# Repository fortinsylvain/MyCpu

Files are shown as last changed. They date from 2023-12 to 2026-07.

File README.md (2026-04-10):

# Homebrew CPU Project

I built this CPU at home using 74LS logic ICs, EEPROMs, RAMs and GALs, driven by curiosity and a desire to understand processor design at a fundamental level.

---

## 🔧 Project Overview
My goal was to create a **fully functional CPU** using a **1-bit ALU**. While this results in relatively slow execution speeds, it allows me to explore the control and datapath mechanisms in detail.

- All **microcode** for the CPU is stored in **two binary files** programmed into 2864 EEPROM chips.
- A custom **microassembler** generates these micro-instructions.

---

## 🧠 Custom CPU PCB Update

After validating the core architecture on a wire-wrap prototype, the custom PCB version of the CPU is now complete. The boards were professionally fabricated by PCBWay, thanks to a generous sponsorship offered by Liam from their marketing team, who discovered the project on GitHub. This support helped transition the design from a hand-built prototype to a professionally produced PCB.

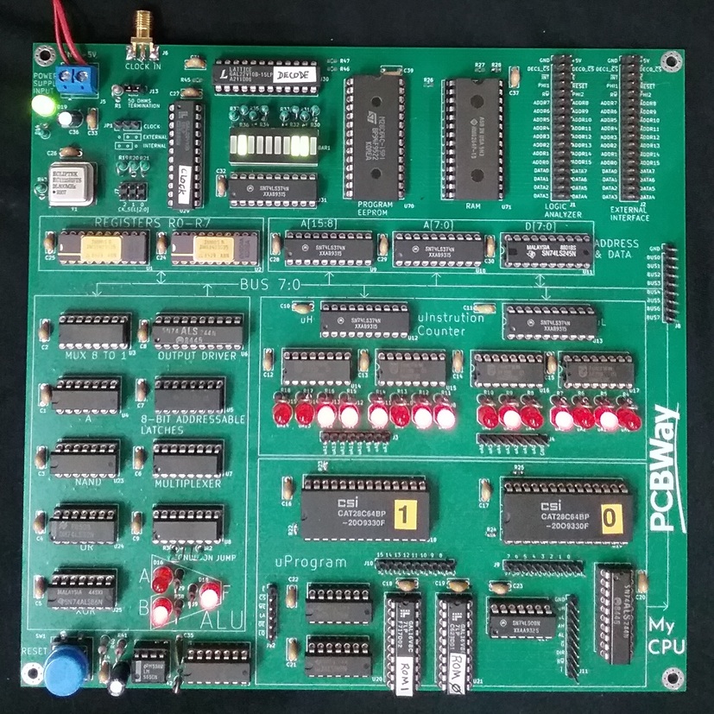
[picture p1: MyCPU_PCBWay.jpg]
KiCad PCB Design


## 🛠️ PCBWay Manufacturing Review

I’m happy to share my experience working with PCBWay for manufacturing the custom PCB version of my CPU project. Here's a quick summary of how it went:

First, I transferred the handwritten schematic into KiCad, then completed the routing for each required part. I was able to find all the necessary components on AliExpress. After carefully checking my Gerber files, it was time to send the design to the factory.

🔁 I was genuinely impressed by PCBWay’s one-click KiCad integration — all design files were submitted automatically to the PCBWay factory with a single click. No file packaging, no ZIP uploads — just click and go! The ordering process was fast and seamless.

🌐 The web interface was intuitive and transparent, allowing me to track each step of the production process in real time.

📦 The PCBs arrived astonishingly quickly, properly boxed and well-protected with excellent packaging. Although I ordered 5 boards, PCBWay generously included 6 — a thoughtful bonus!

The soldering process went smoothly. I used footprints optimized for hand soldering, with larger pads to make it easier to work with. Only a couple of 0603 surface-mount resistors are present on the board.

🔌 First power-on: the board worked on the first try!
I reused the same microcode and program EEPROM, along with the GAL, that were previously tested on the wire-wrap prototype — total success.

Since the new board has a solid ground plane, I expect it will run faster than the prototype, with improved signal integrity. I plan to validate this with an oscilloscope soon — stay tuned for updates!

🌍 There’s a strong online community around PCBWay, full of shared open-source hardware projects — very inspiring!

## 🧠 Board design files
[Download Schematic PDF](Kicad/MyCPU_Schematic.pdf)

## 🧵 Wire-Wrap Prototype

Before moving to a PCB, I built a **wire-wrap prototype** to test the design on real hardware. This stage was essential for debugging the microcode, verifying timing, and refining the instruction set.

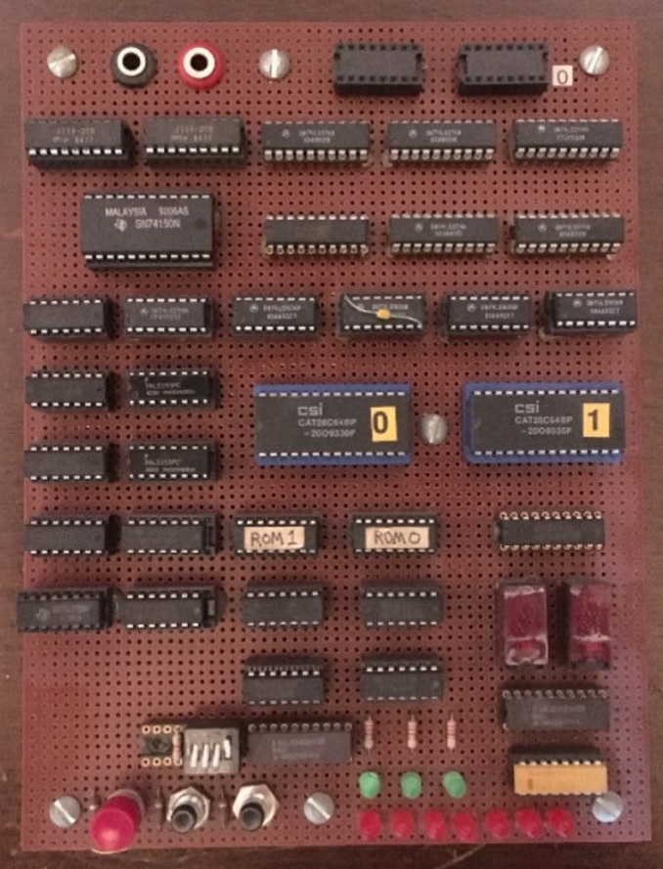
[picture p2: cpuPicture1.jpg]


Here’s a picture of the back — a lot of patience was required!
Amazingly, it's still holding together and executing code after 30 years.

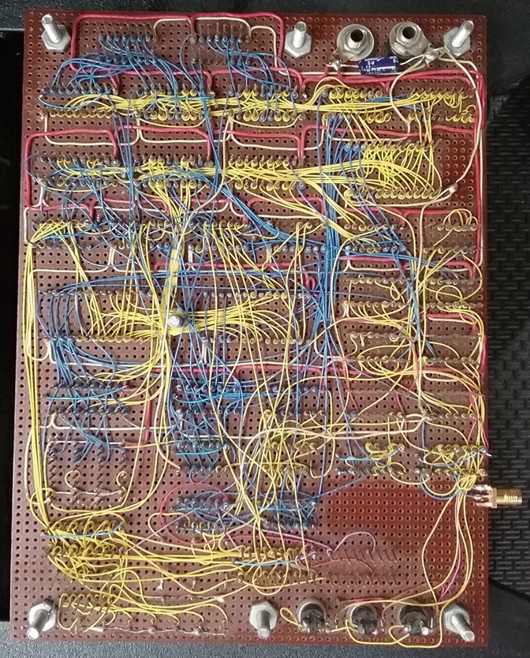
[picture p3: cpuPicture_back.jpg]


Wire-wrapping made it easier to make changes during development while still providing a reliable and compact way to interconnect components.

---

## Microcode and Assembler

💾 [Download Microcode Source](uCodeAssembler/urom.lst)  
💾 [Download Microcode Assembler](uCodeAssembler/UctMicroAssembler/Program.cs)  
💾 [Download Opcode Assembler](opCodeAssembler/Program.cs)  
💾 [Download Diagnostic Program](opCodeAssembler/examples/diag.asm)  

---
## GAL source files
In the PCB version of MyCPU i make use of programmable logic devices (GALs) for clock phase generation, address decoding, and microcode ROM decoding tables.
The source files were compiled using WinCupl, and the chips were programmed using a TL866II Plus programmer.

💾 [Download GAL22V10 Clock](GAL/Clock/CLOCK.PLD)
💾 [Download GAL22V10 Decoder](GAL/Decoder/DECODER.PLD)
💾 [Download GAL16V8 ROM0](GAL/Rom0/ROM0.PLD)
💾 [Download GAL16V8 ROM1](GAL/Rom1/ROM1.PLD)

## 🧠 Register Implementation on RAM

The design uses address-mapped RAM to support the CPU’s operation. This approach saves chip count, though at the cost of execution speed.

The following registers are implemented in RAM:
- Instruction Pointer
- Register A
- Carry Flag
- Equal Flag
- Index Register
- Stack Pointer
- The Stack

Here is the memory address map:

0000H - 17FFH Total RAM space
-----------------------------
* 0000H - 17FFH Total RAM space
* 0000H - 00FFH Stack
* 0100H - 17EF  Free for application
* 1FF0H SP      Stack Pointer 8 bit
* 1FF1H JSH     Temporary storage for JSR MSB address
* 1FF2H JSL          "       "     "   "  LSB    "
* 1FF3H XH      Index Register MSB
* 1FF4H XL      Index Register LSB
* 1FFAH E       bit<0> Equal Status bit
* 1FFBH C       bit<0> Carry Status bit
* 1FFCH A       Register
* 1FFEH IPH	    Instruction Pointer MSB
* 1FFFH IPL     Instruction Pointer MSB
* C000H         LED port
* E000H - F000H EEPROM for application program

---

## System Overview

### Top-Level Architecture Diagram  
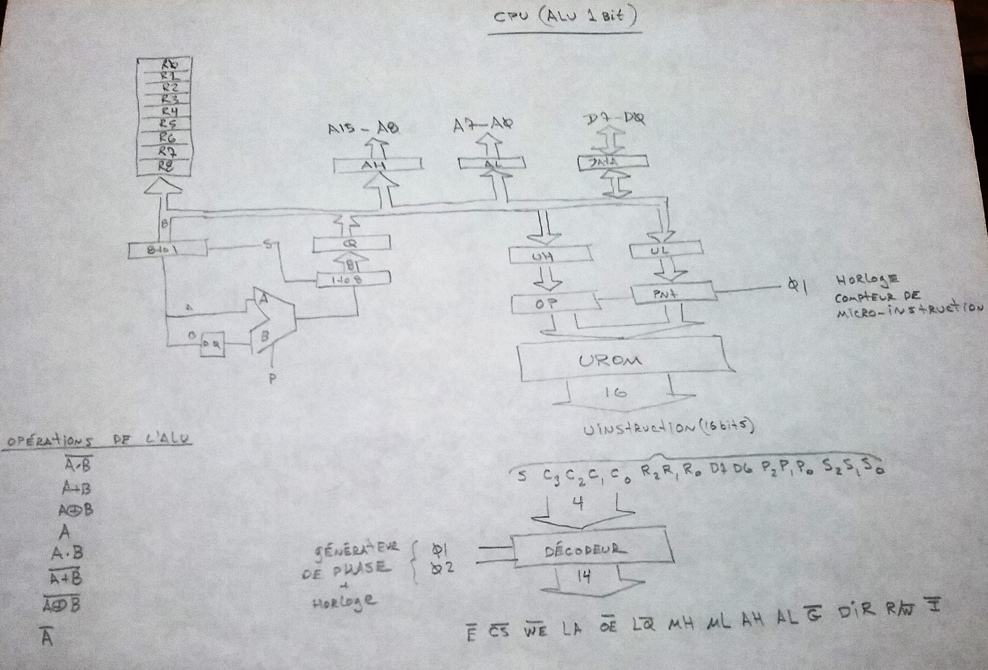
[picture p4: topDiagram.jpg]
Top-Level Diagram


### Hand-Written CPU Schematic  
When I started this project back in 1995, I didn’t have access to schematic capture software or a decent computer that could run it. I only had an IBM Personal Computer XT, so I used pen and paper to sketch how the electronic components were connected.

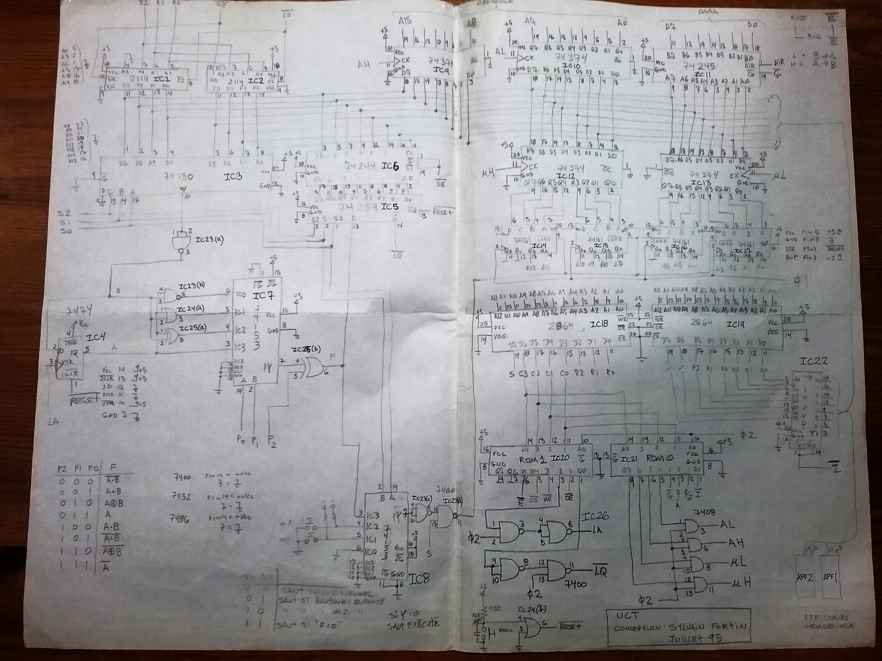
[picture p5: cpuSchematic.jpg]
CPU Schematic


### CPU Board Layout View  
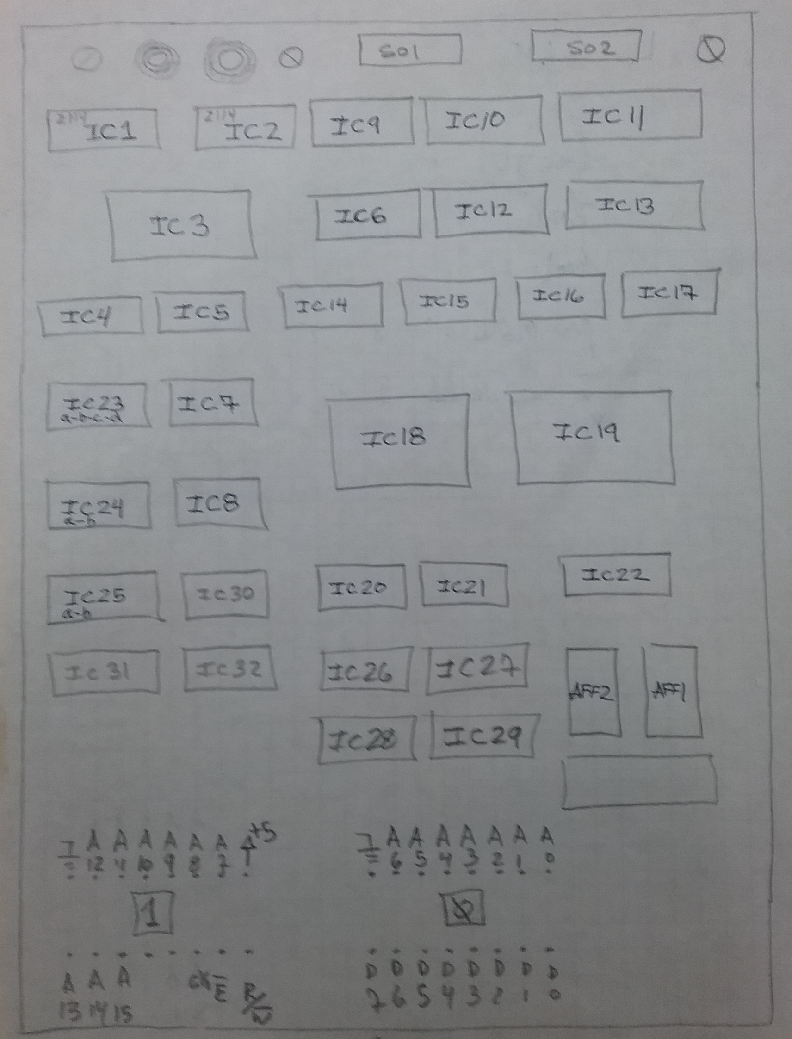
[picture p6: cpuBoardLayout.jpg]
CPU Board Layout


---

## Microcode and Control ROMs

The microcode is stored in two 2864 EEPROM ICs.
Originally, a BASIC program was used to translate a text file of micro-instructions into a .hex file.
A homemade EEPROM programmer was built to write these files via the parallel port of an IBM PC XT.

Today, a modern C# program performs the same translation into .hex format for programming.

The ROM decoding table encodes how data moves between components. This reduces the number of control bits required by expanding microcode control using external PROMs.

- ROM chips: **IC20** and **IC21** (74S188, 256×1 Open Collector PROMs)
- These are *one-time programmable* PROMs.
- Several chips were sacrificed before the correct decoding table was finalized.

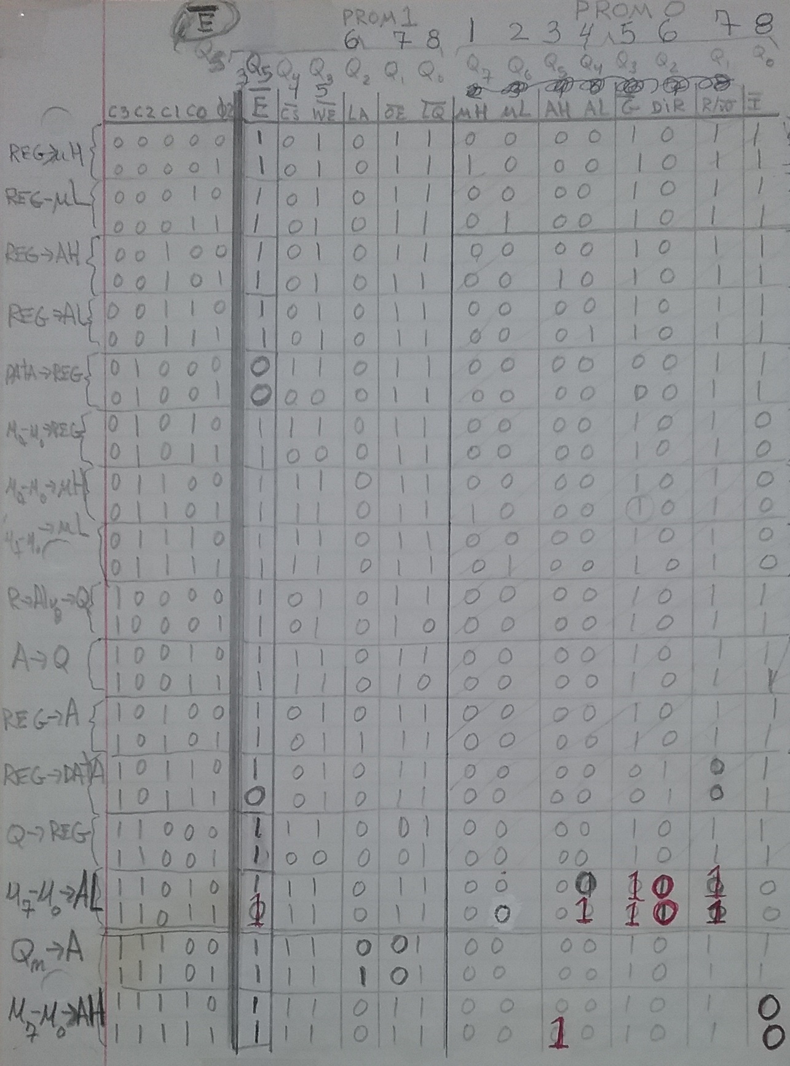
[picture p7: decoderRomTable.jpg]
Decoder ROM Table


In the PCB version of the board, two GAL16V8 replaces the PROMs to implement the decoding table, offering greater flexibility and eliminating the need for one-time programmable chips.

---

## I/O Board Schematic
Wire wrap proto required a second board to include the following:
- RAM
- EEPROM (for application program)
- LEDs for visual feedback

The PCB version includes all of these components on a single board.

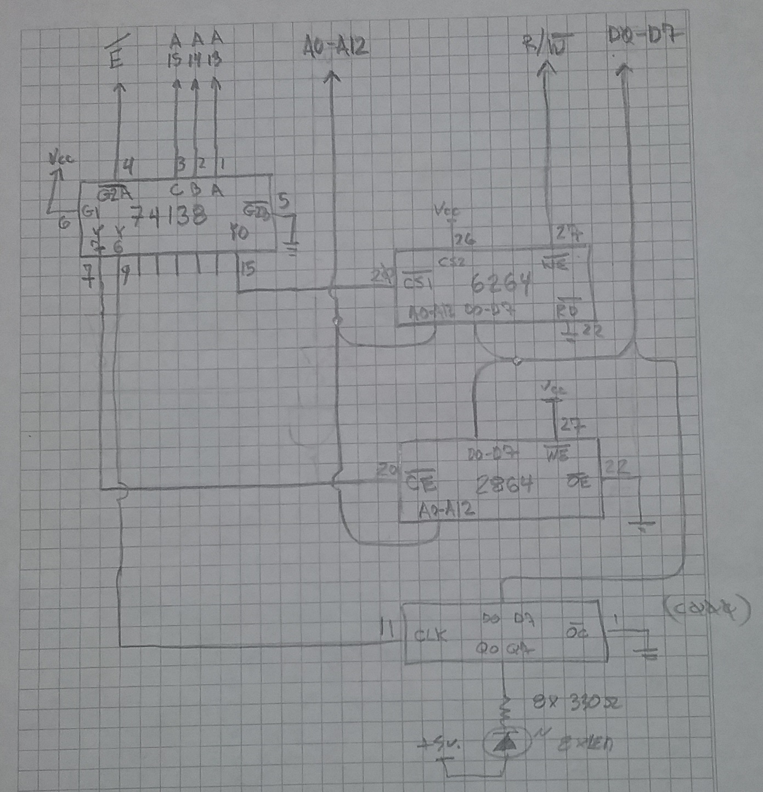
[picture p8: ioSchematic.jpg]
I/O Schematic


---

## Debugging Setup

Initially, I was single-stepping using push switches, LEDs, and a pair of classic TIL311 hex displays to monitor the 8-bit data bus on the wire-wrap prototype, but it quickly stopped being fun. When bugs like stack corruption became too tricky to debug, I decided to get an Agilent 1670G Logic Analyzer. I found one on eBay for 510 CAD, which seemed like a reasonable price—I never thought I’d own one! It’s the color LCD version, so now I get to see the word in color.

With the analyzer, I can trigger on specific conditions and even do some reverse assembly of the microcode using basic symbolic decoding. It allow recording of detailed intructions traces. Quite cool!

### Final Wire-Wrap Assembly with Logic Analyzer  
Here the Logic analyzer connected to **MyCpu** for a debug session.
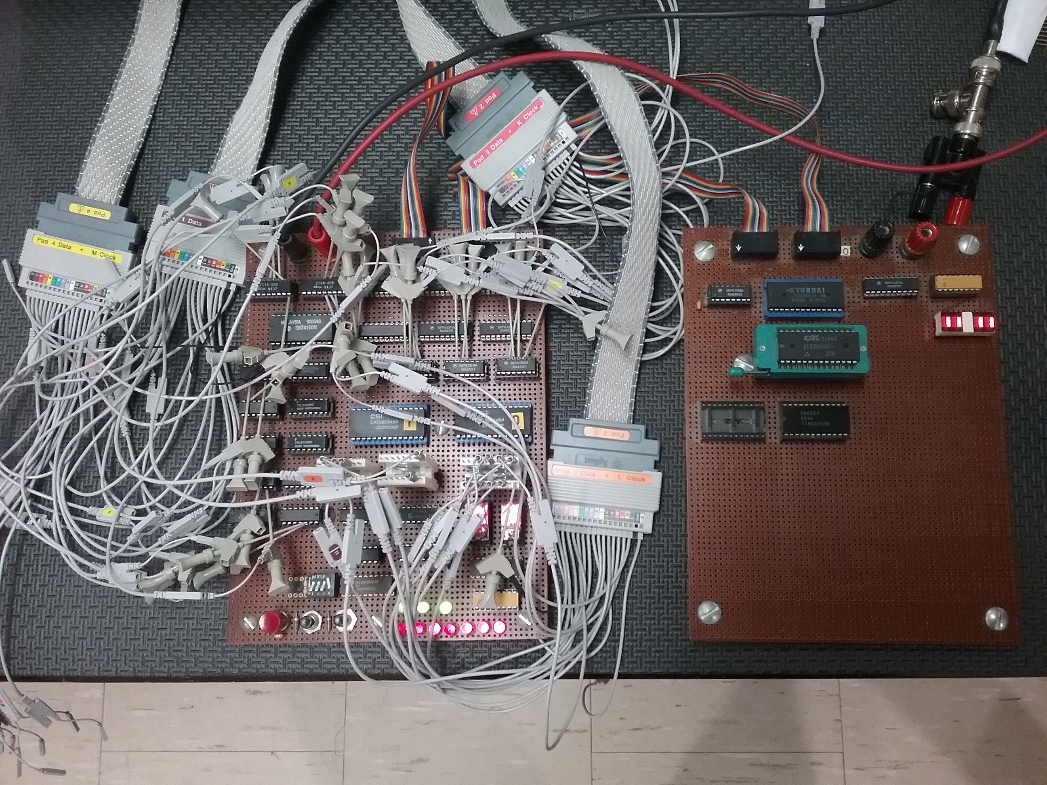
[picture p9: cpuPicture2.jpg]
Wire-Wrap and Logic Analyzer


### Microcode View on Logic Analyzer  
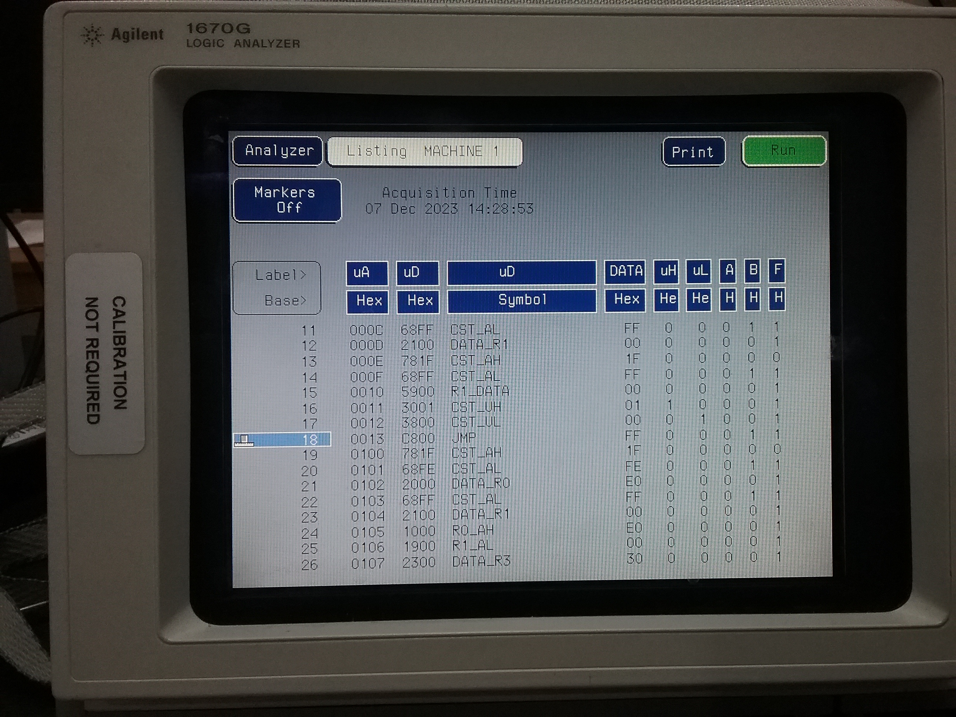
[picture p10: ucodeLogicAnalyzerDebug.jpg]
Microcode Disassembly


---

# MyCPU Instruction Set

This document describes the instruction set of the **MyCPU homebrew processor**.

---

# 📘 Overview

- 8-bit accumulator architecture (A, X registers)
- 16-bit addressing support
- Flags: E (equal/zero), C (carry)
- Stack support (SP-based)

---

# 📑 Instruction Set

---

## Data Movement

| Mnemonic | OpCode | Bytes | Mode | Flags | Description |
|---|---|---|---|---|---|
| LDA #0x** | 0x30 | 1 | Hex | - | Load immediate into A |
| LDA 0x**** | 0x2A | 2 | Hex | - | Load A from memory (absolute) |
| LDA @ | 0x2A | 2 | Symbol | - | Load A from memory (symbolic) |
| LDA (X) | 0x0A | 0 | Hex | - | Load A from memory indexed by X |
| STA 0x**** | 0x31 | 2 | Hex | - | Store A into memory (absolute) |
| STA @ | 0x31 | 2 | Symbol | - | Store A into memory (symbolic) |
| LDX 0x**** | 0x34 | 2 | Hex | - | Load X from memory |
| LDX @ | 0x34 | 2 | Symbol | - | Load X from symbolic address |
| STX 0x**** | 0x16 | 2 | Hex | - | Store X into memory |
| STX @ | 0x16 | 2 | Symbol | - | Store X into memory |

---

## Arithmetic / Logic

| Mnemonic | OpCode | Bytes | Mode | Flags | Description |
|---|---|---|---|---|---|
| ADDA #0x** | 0x2F | 1 | Hex | C | Add immediate to A |
| ADDA 0x**** | 0x29 | 2 | Hex | C | Add memory to A |
| ADDA @ | 0x29 | 2 | Symbol | C | Add memory to A (symbolic) |
| ADCA #0x** | 0x2E | 1 | Hex | C | Add immediate + carry |
| ADCA 0x**** | 0x28 | 2 | Hex | C | Add memory + carry |
| ANDA #0x** | 0x33 | 1 | Hex | - | Logical AND with A |
| ORA #0x** | 0x17 | 1 | Hex | - | Logical OR with A |
| XORA #0x** | 0x18 | 1 | Hex | - | Logical XOR with A |
| NOTA | 0x19 | 0 | Hex | - | Bitwise NOT A |
| INCA | 0x03 | 0 | Hex | E | Increment A |
| DECA | 0x20 | 0 | Hex | E | Decrement A |
| CMPA #0x** | 0x2D | 1 | Hex | E,C | Compare A with immediate |

---

## Control Flow

| Mnemonic | OpCode | Bytes | Mode | Flags | Description |
|---|---|---|---|---|---|
| JMP 0x**** | 0x32 | 2 | Hex | - | Unconditional jump |
| JMP @ | 0x32 | 2 | Symbol | - | Unconditional jump (symbolic) |
| JEQ 0x**** | 0x2C | 2 | Hex | - | Jump if equal |
| JEQ @ | 0x2C | 2 | Symbol | - | Jump if equal (symbolic) |
| JNE 0x**** | 0x2B | 2 | Hex | - | Jump if not equal |
| JNE @ | 0x2B | 2 | Symbol | - | Jump if not equal |
| JRA 0x** | 0x0C | 1 | Hex | - | Relative jump |
| JRA @ | 0x0C | 1 | Relative | - | Relative jump (symbol) |
| JRNC @ | 0x0F | 1 | Relative | - | Jump if no carry |
| JRUGE @ | 0x23 | 1 | Relative | - | Jump if unsigned ≥ |

---

## Stack & Subroutines

| Mnemonic | OpCode | Bytes | Mode | Flags | Description |
|---|---|---|---|---|---|
| JSR 0x**** | 0x06 | 2 | Hex | - | Jump to subroutine |
| JSR @ | 0x06 | 2 | Symbol | - | Jump to subroutine |
| RTS | 0x07 | 0 | Hex | - | Return from subroutine |
| PSHA | 0x24 | 0 | Hex | - | Push A to stack |
| POPA | 0x25 | 0 | Hex | - | Pop stack into A |

---

## Shift / Bit Operations

| Mnemonic | OpCode | Bytes | Mode | Flags | Description |
|---|---|---|---|---|---|
| SLLA | 0x0E | 0 | Hex | C | Shift left logical |
| SRLA | 0x0D | 0 | Hex | C | Shift right logical |
| RRCA | 0x10 | 0 | Hex | C | Rotate right through carry |
| RRC @ | 0x14 | 2 | Symbol | C | Rotate memory right |
| SRL @ | 0x15 | 2 | Symbol | C | Shift memory right |

---

## System / Misc

| Mnemonic | OpCode | Bytes | Mode | Flags | Description |
|---|---|---|---|---|---|
| NOP | 0x09 | 0 | Hex | - | No operation |
| STOP | 0x08 | 0 | Hex | - | Halt execution |
| SCF | 0x12 | 0 | Hex | C | Set carry flag |
| RCF | 0x11 | 0 | Hex | C | Reset carry flag |
| CLRA | 0x26 | 0 | Hex | E | Clear A |
| CLRX | 0x1E | 0 | Hex | E | Clear X |

---

## Memory / Data

| Mnemonic | OpCode | Bytes | Mode | Flags | Description |
|---|---|---|---|---|---|
| DB 0x** | 0x00 | 0 | Hex | - | Define byte |
| .ASCII "@" | 0x00 | 0 | Ascii | - | Store ASCII string |
| EQU 0x**** | 0x00 | 0 | Hex | - | Define constant |

---

# 🧠 Notes

- `E` = equality / zero flag
- `C` = carry flag
- `@` = symbolic addressing
- `0x****` = 16-bit address
- `#0x**` = immediate value

---

# 🚀 Generated by MyCPU Assembler

---

## Inspiration and Community

I began documenting this project after discovering **other wonderful homebrew machines** featured on:

👉 [Homebuilt CPUs WebRing](https://www.homebrewcpuring.org)

### Join the Ring!

Interested in joining the Homebuilt CPUs WebRing?

- Contact **Warren** (email address is obfuscated—replace `[at]` with `@`)
- Mention your page URL and request to join
- Add the WebRing code fragment to your site

📌 **Note:** The ring is for *actual home-built CPUs*. Emulations of commercial parts are OK.  
However, projects must be *partially or fully built*—**paper designs don’t qualify**.  
Technologies used can include **relays**, **TTL**, **CMOS**, **FPGAs**, etc.

## License
This project is licensed under the MIT License – see the [LICENSE](license.txt) file for details.

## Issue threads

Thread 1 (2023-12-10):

Rename source file to .asm

fortinsylvain, 2023-12-10:
Rename source file extension to .asm to avoid confusion and help github to associate it to assembly language.

fortinsylvain, 2023-12-14:
Code was changed.

Closed 2023-12-14.

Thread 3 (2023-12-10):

Add stack related instructions

fortinsylvain, 2023-12-10:
Current microcode version does not support operation on stack. Add micro instruction to do push, pop and jump to subroutine.

fortinsylvain, 2023-12-31:
jsr and rts was fixed in the microcode

Closed 2023-12-31.

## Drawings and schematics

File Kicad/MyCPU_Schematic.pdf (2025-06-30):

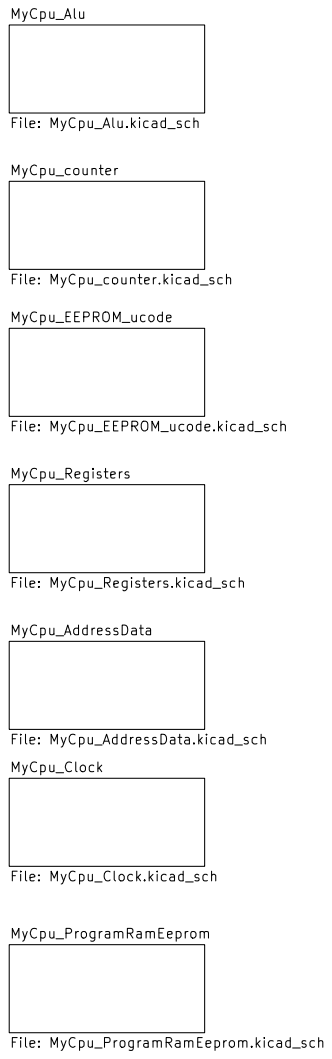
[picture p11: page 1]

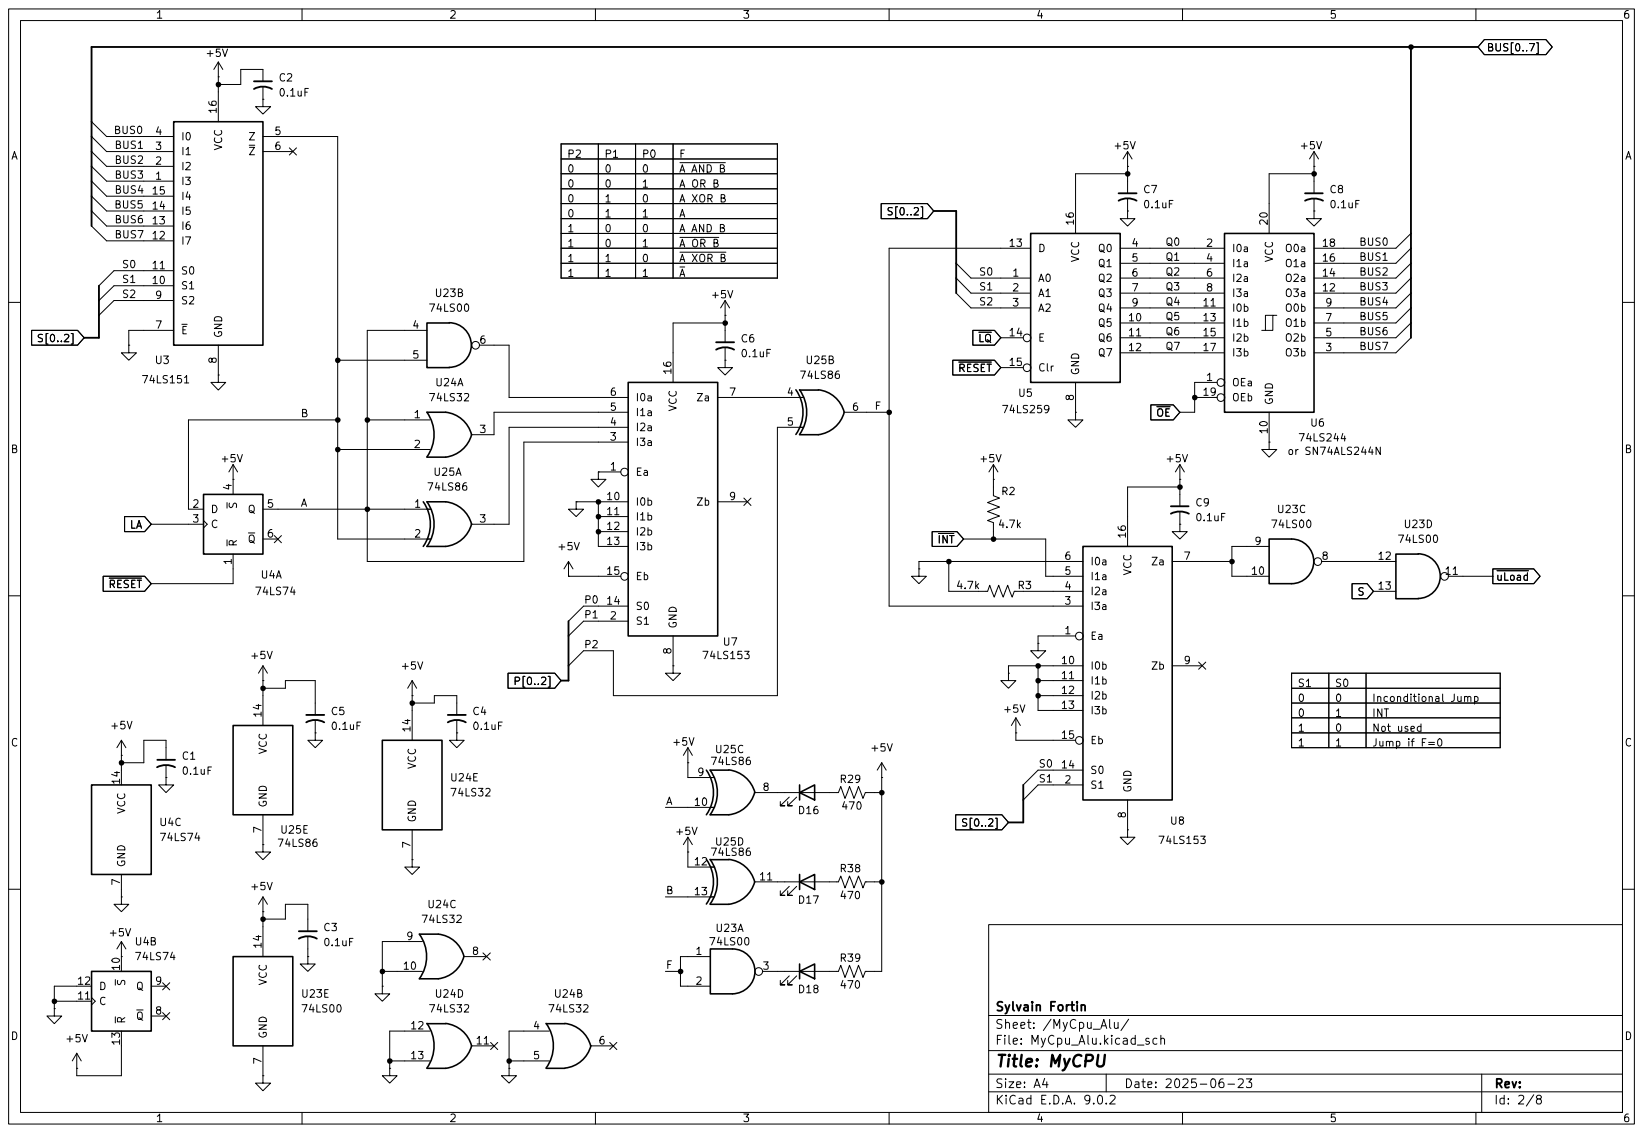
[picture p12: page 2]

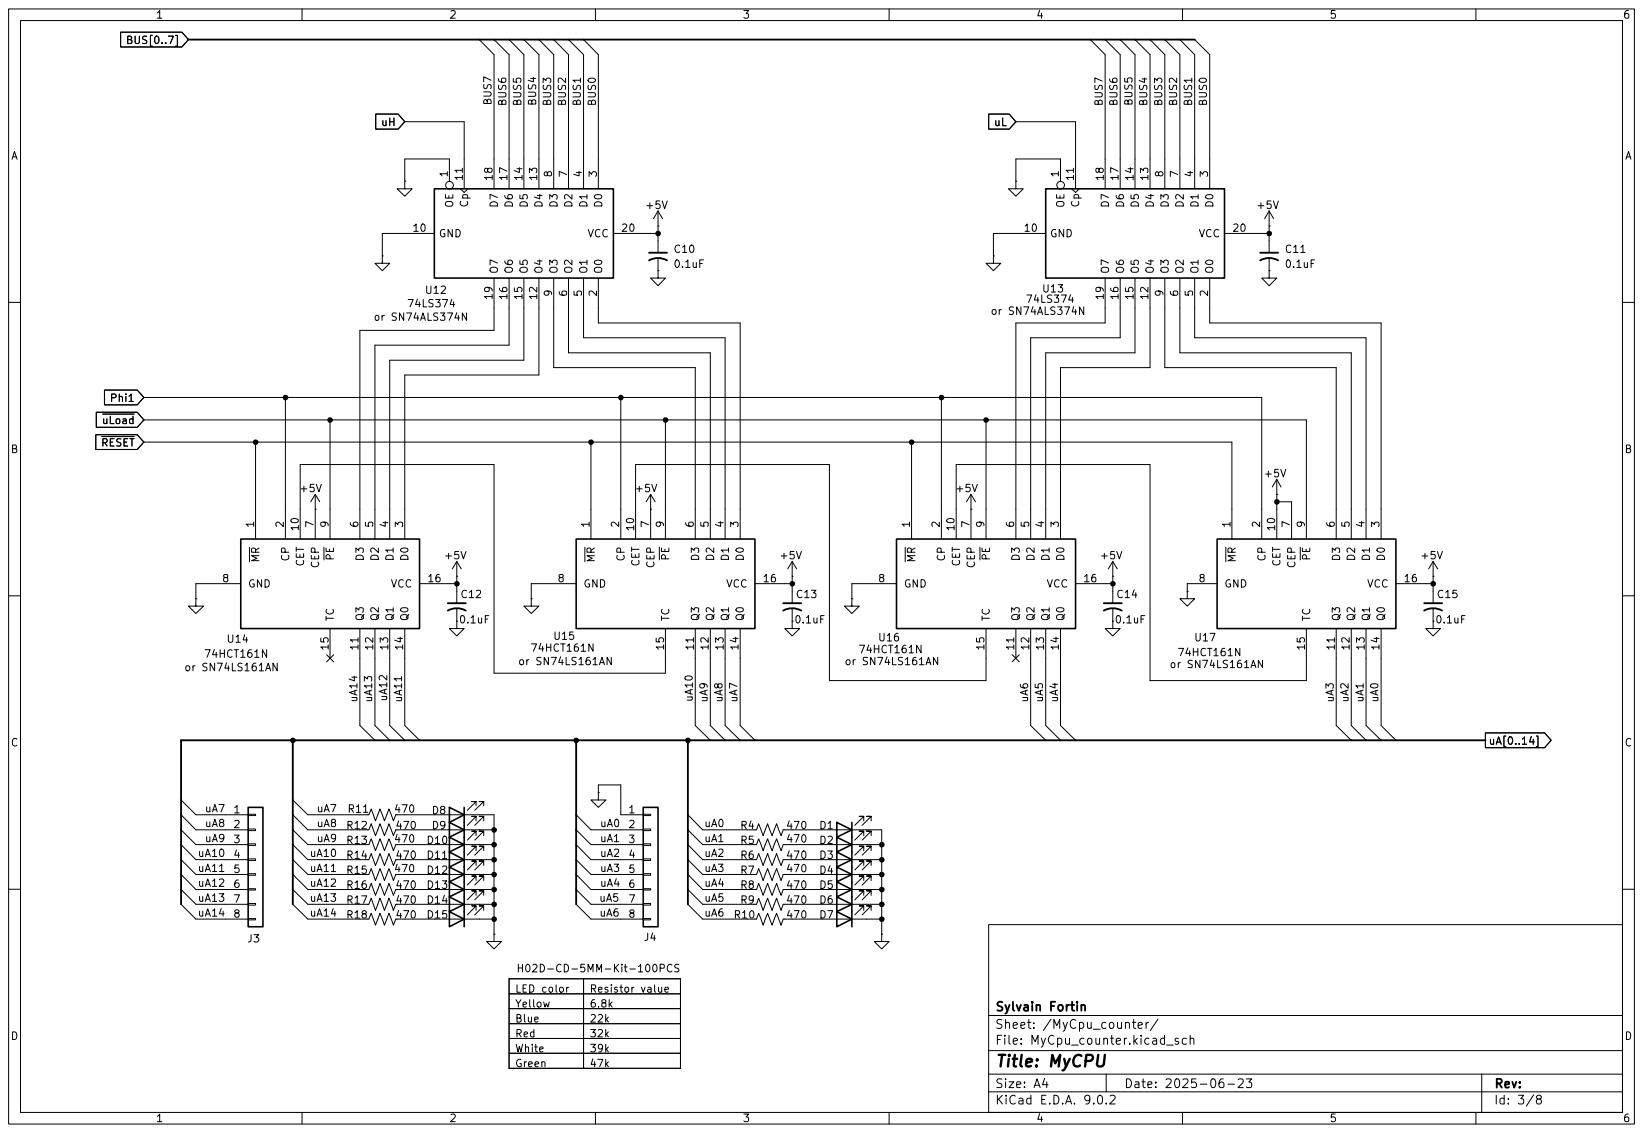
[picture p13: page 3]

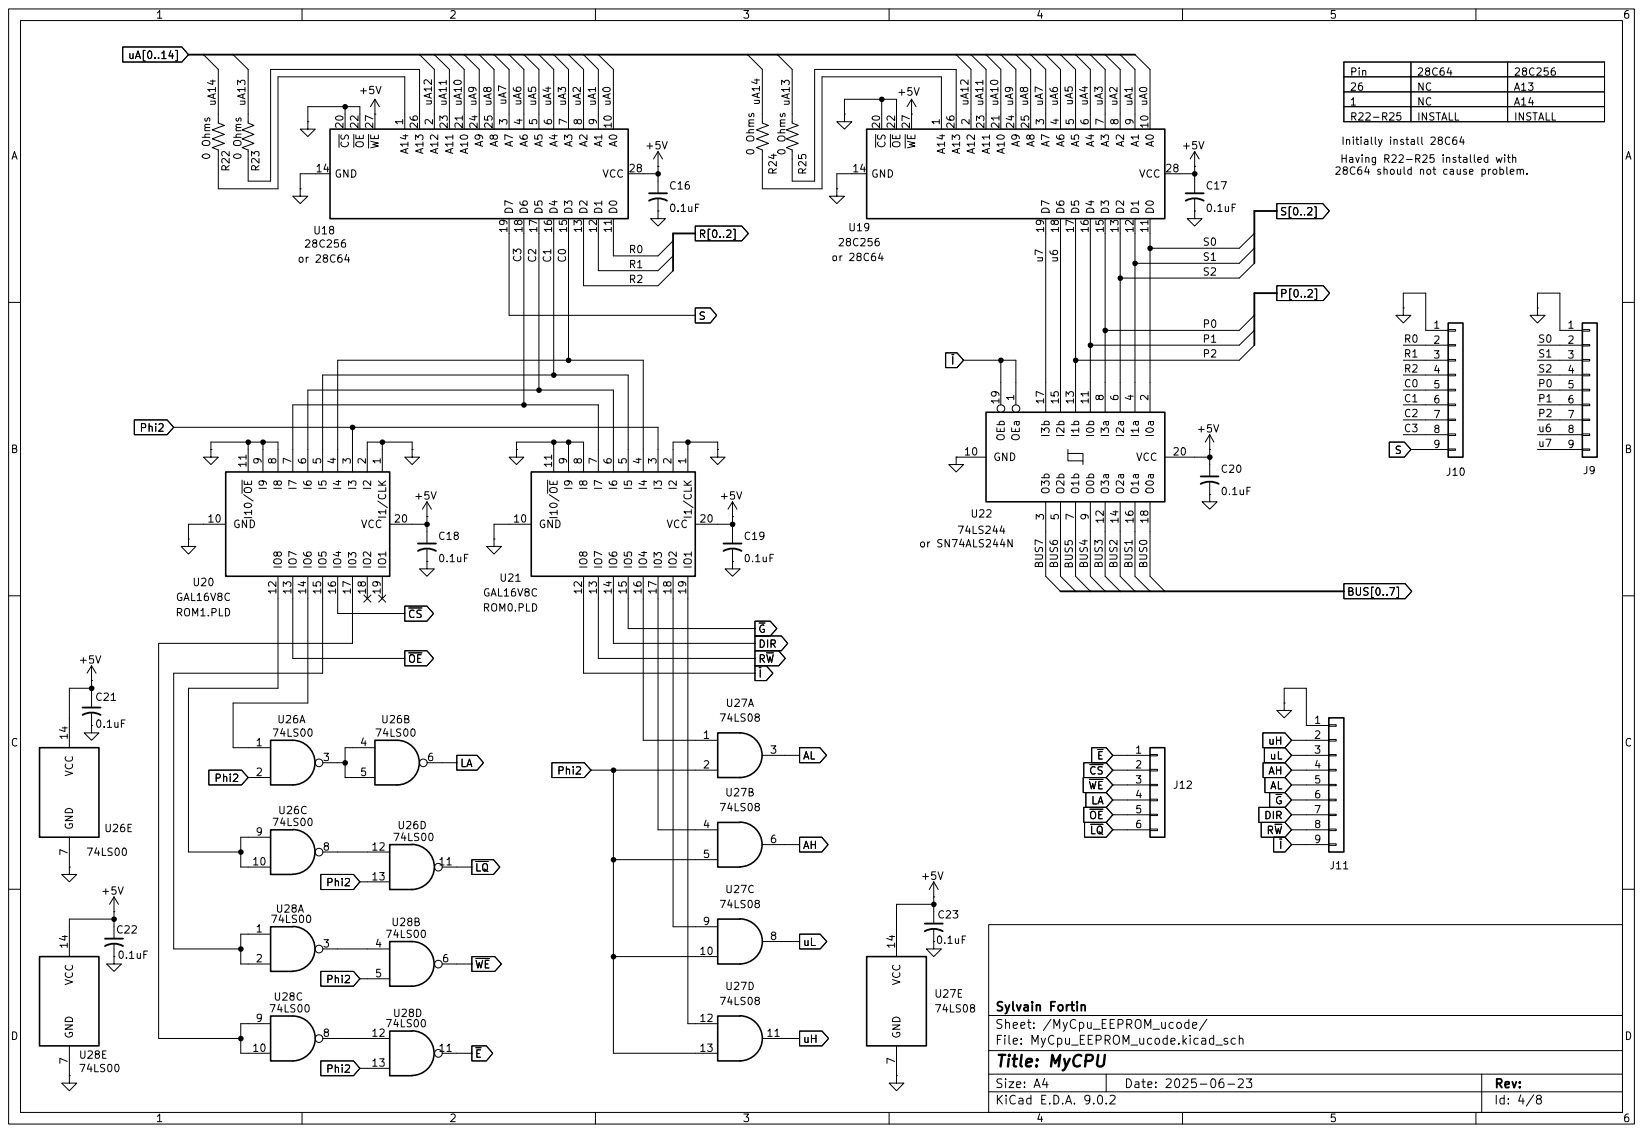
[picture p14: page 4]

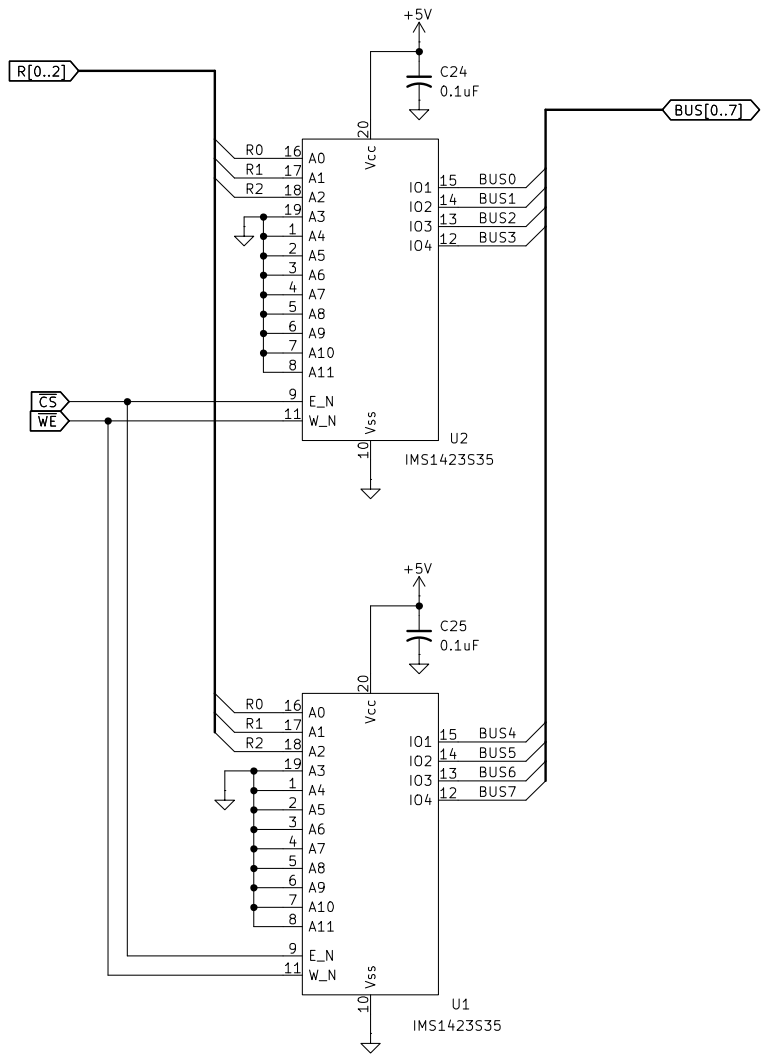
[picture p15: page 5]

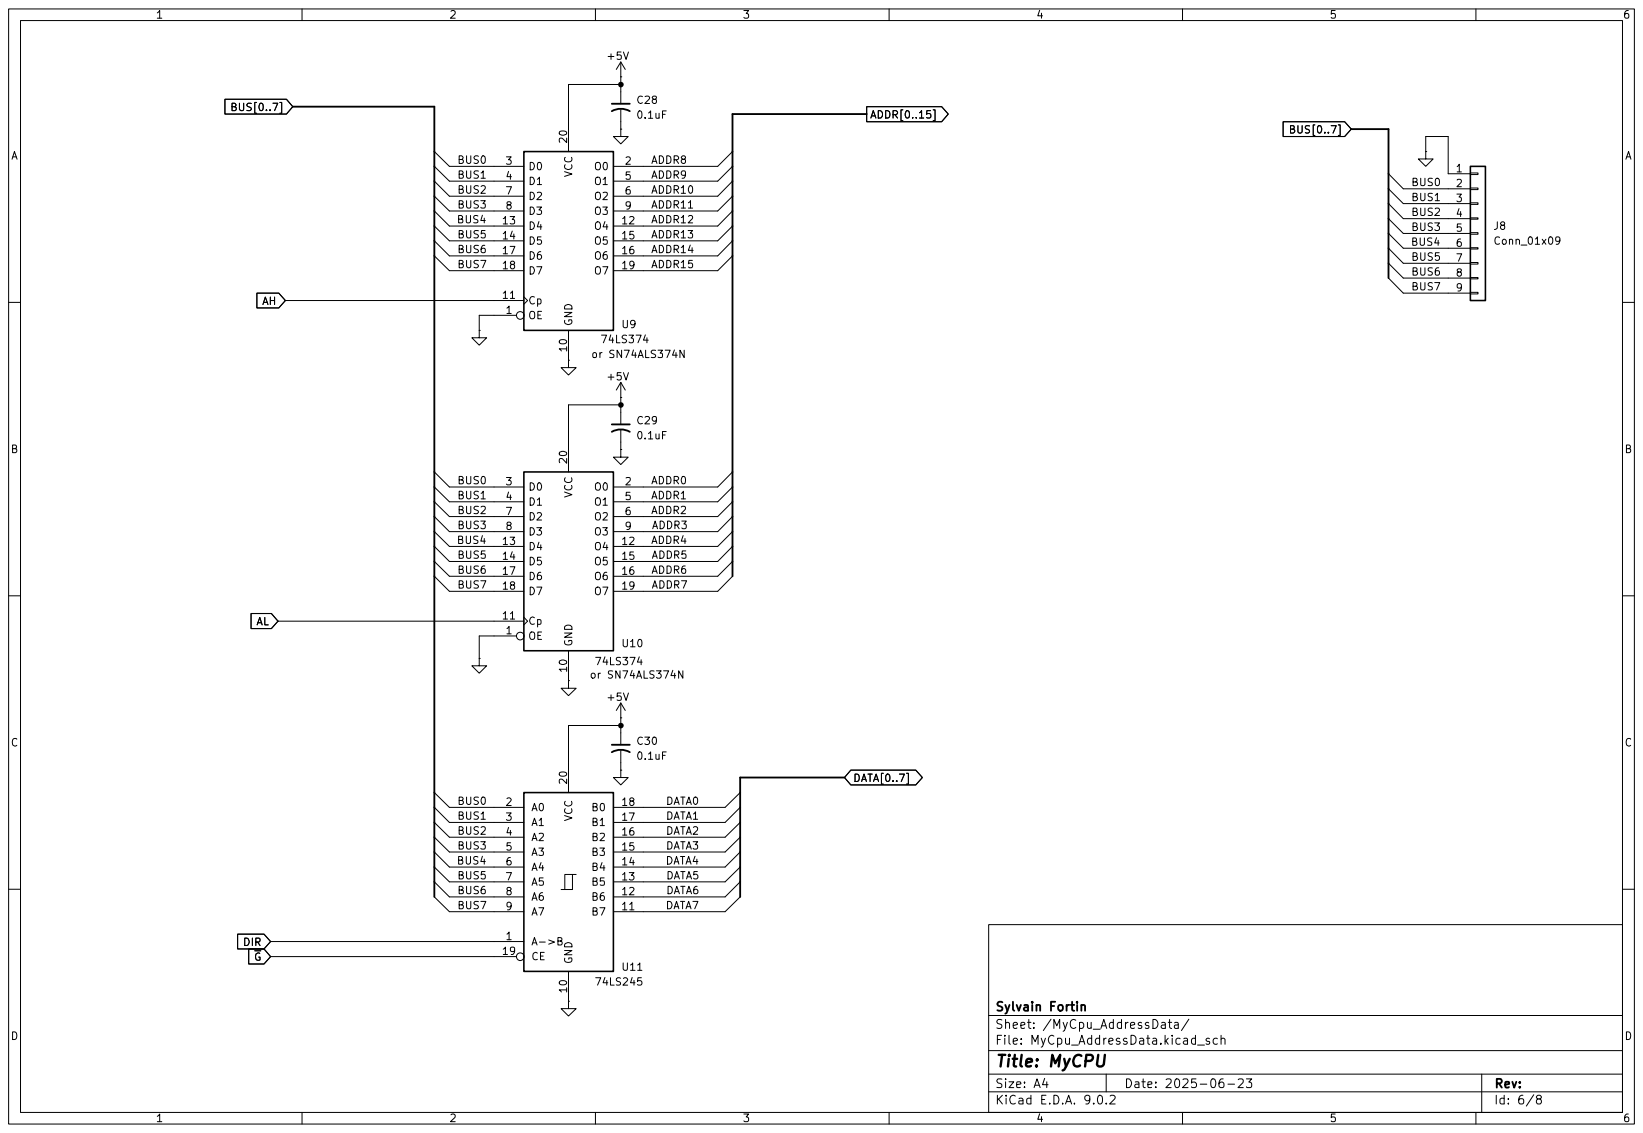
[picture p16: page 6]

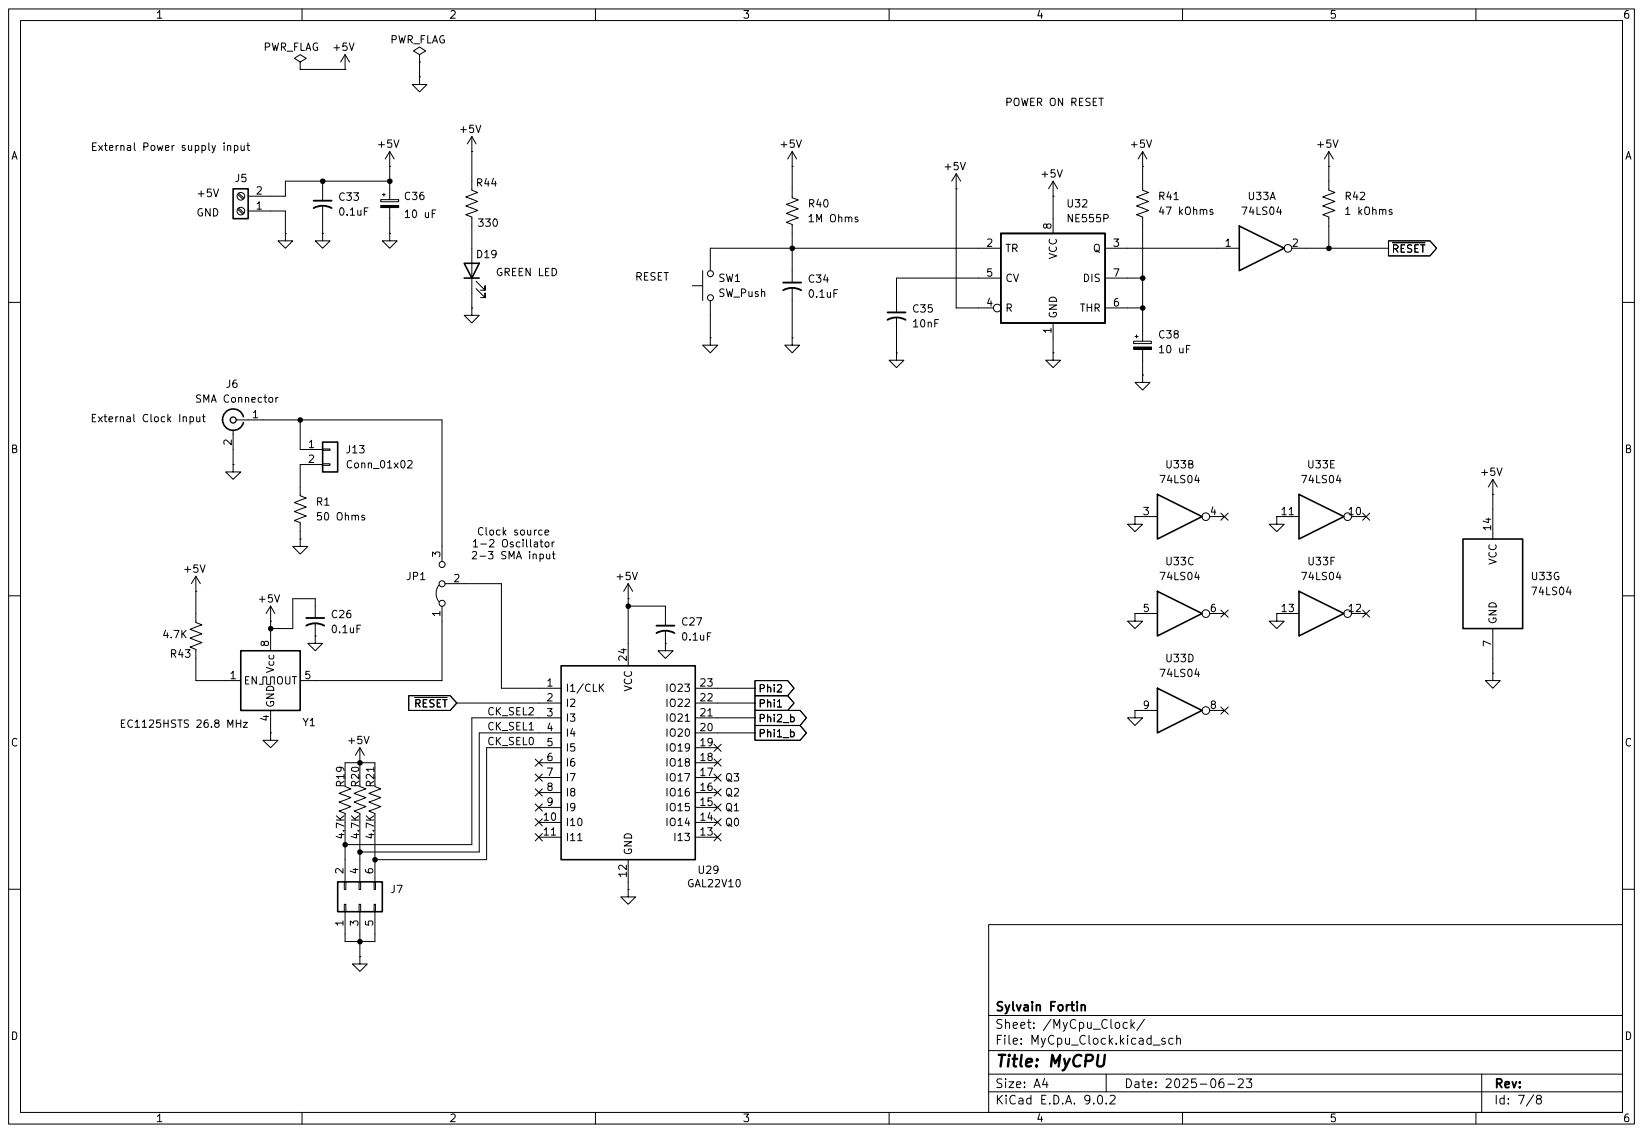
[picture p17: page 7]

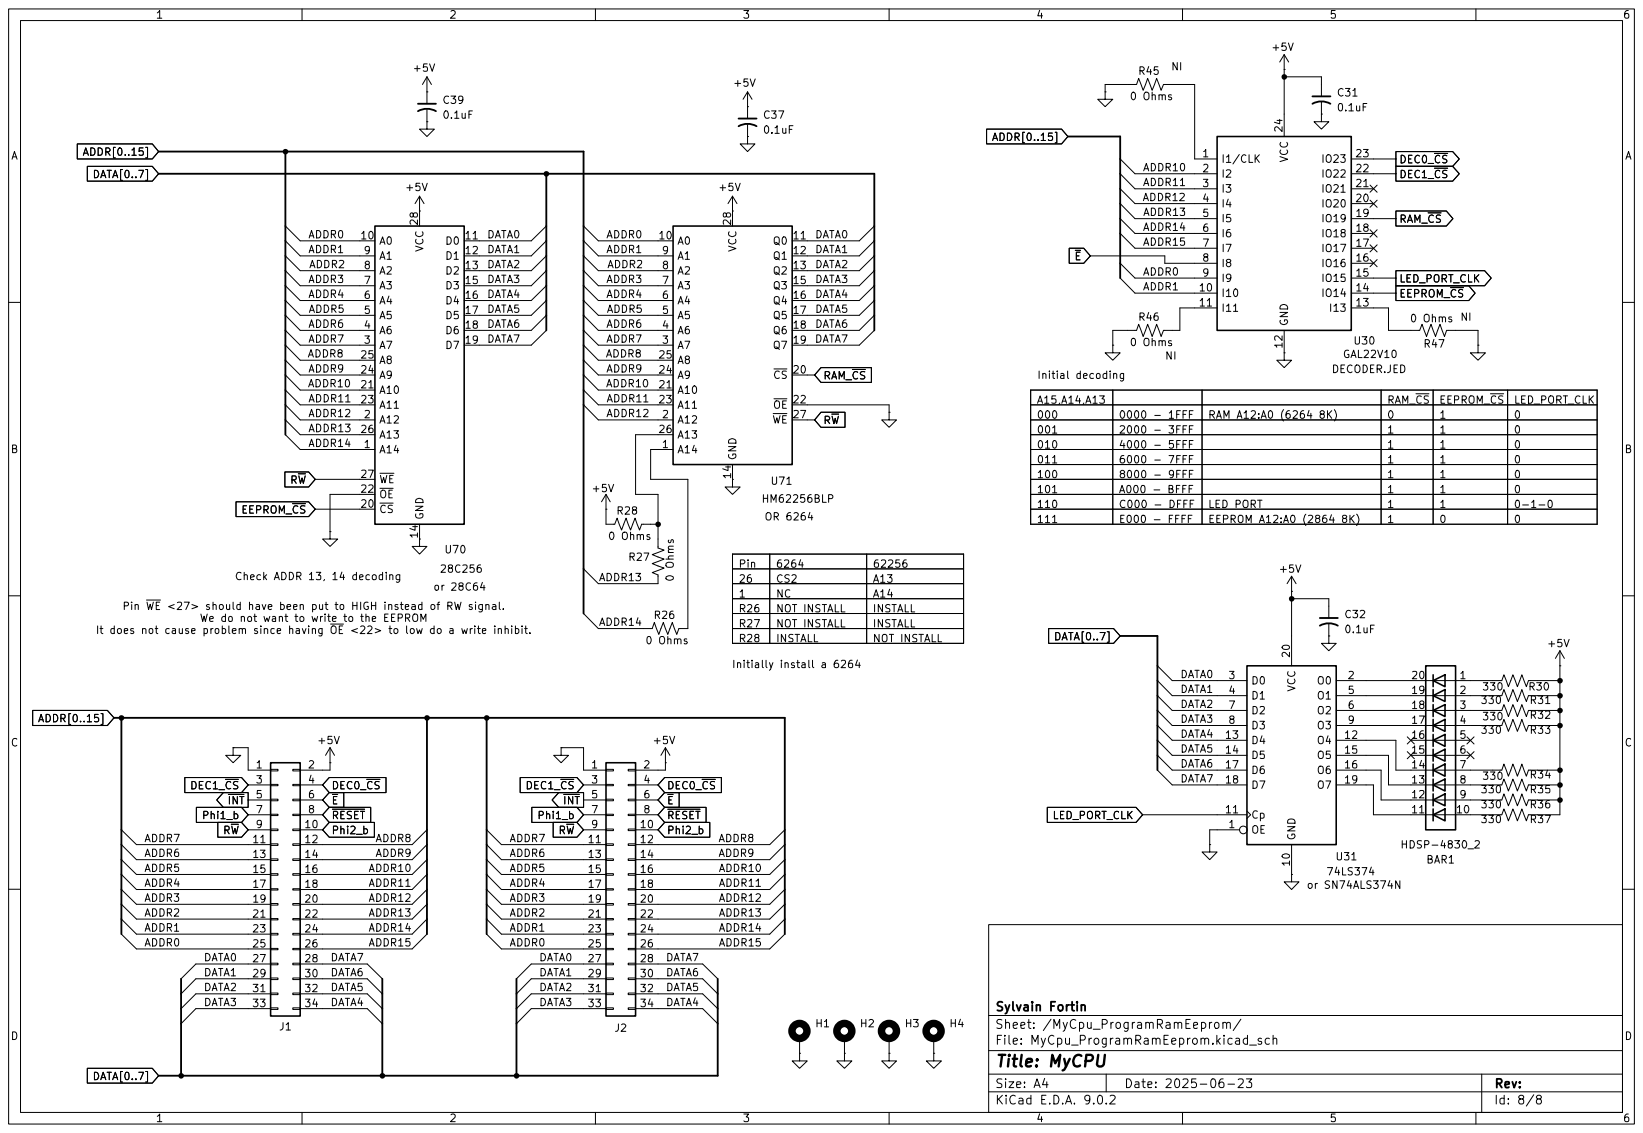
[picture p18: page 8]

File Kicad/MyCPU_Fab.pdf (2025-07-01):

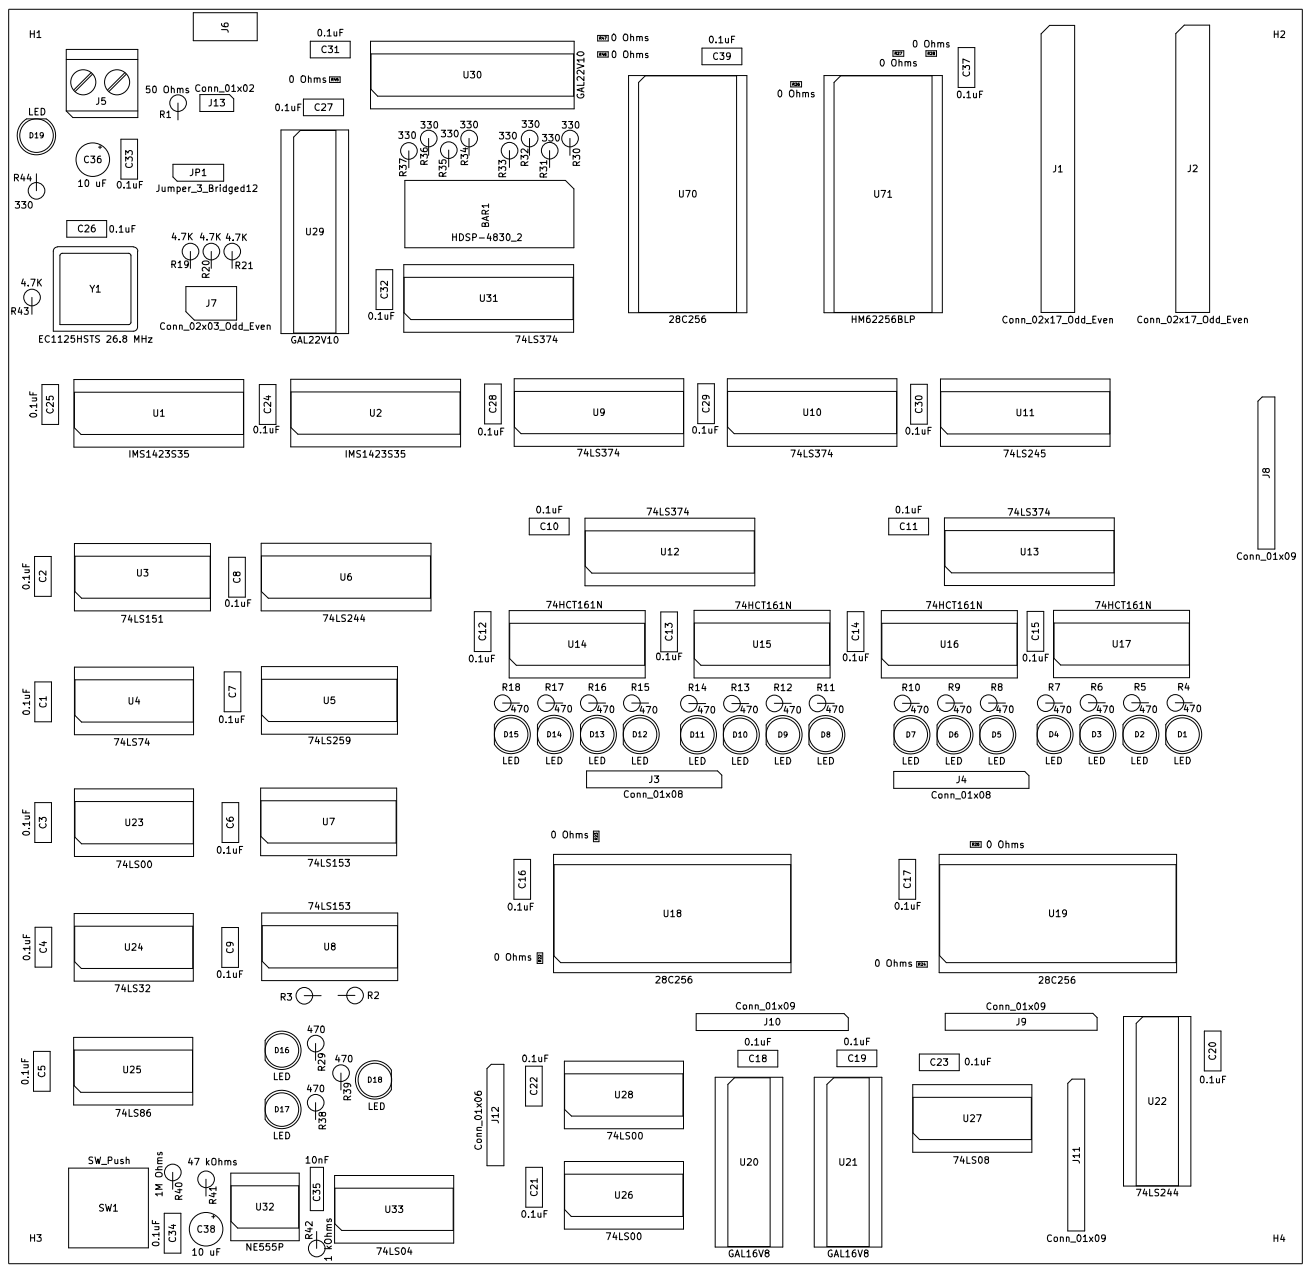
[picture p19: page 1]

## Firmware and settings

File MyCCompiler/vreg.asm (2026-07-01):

; virtual registers
;-----------------------------------------------------------------------------
; ?b15 ?b14 ?b13 ?b12 | ?b11 ?b10 ?b9 ?b8 | ?b7 ?b6 ?b5 ?b4 | ?b3 ?b2 ?b1 ?b0 |  8 bits
;    ?w7       ?w6    |    ?w5      ?w4   |   ?w3     ?w2   |   ?w1     ?w0   | 16 bits
;         ?l3         |         ?l2       |       ?l1       |       ?l0       | 32 bits
;-----------------------------------------------------------------------------

?b15     EQU 0x0000
?b14     EQU 0x0001
?b13     EQU 0x0002
?b12     EQU 0x0003
?b11     EQU 0x0004
?b10     EQU 0x0005
?b9      EQU 0x0006
?b8      EQU 0x0007
?b7      EQU 0x0008
?b6      EQU 0x0009
?b5      EQU 0x000A
?b4      EQU 0x000B
?b3      EQU 0x000C
?b2      EQU 0x000D
?b1      EQU 0x000E
?b0      EQU 0x000F

?w7      EQU 0x0000  ; ?b15:?b14
?w6      EQU 0x0002  ; ?b13:?b12
?w5      EQU 0x0004  ; ?b11:?b10
?w4      EQU 0x0006  ; ?b9:?b8
?w3      EQU 0x0008  ; ?b7:?b6
?w2      EQU 0x000A  ; ?b5:?b4
?w1      EQU 0x000C  ; ?b3:?b2
?w0      EQU 0x000E  ; ?b1:?b0

?l3      EQU 0x0000  ; ?b15,?b14,?b13,?b12
?l2      EQU 0x0004  ; ?b11,?b10,?b9,?b8
?l1      EQU 0x0008  ; ?b7,?b6,?b5,?b4
?l0      EQU 0x000C  ; ?b3,?b2,?b1,?b0

; ------------------ mov32 implementations ------------------
?mov32_l0_l0:
    LDA ?b0
    STA ?b0
    LDA ?b1
    STA ?b1
    LDA ?b2
    STA ?b2
    LDA ?b3
    STA ?b3
    RTS

?mov32_l0_l1:
    LDA ?b4
    STA ?b0
    LDA ?b5
    STA ?b1
    LDA ?b6
    STA ?b2
    LDA ?b7
    STA ?b3
    RTS

?mov32_l0_l2:
    LDA ?b8
    STA ?b0
    LDA ?b9
    STA ?b1
    LDA ?b10
    STA ?b2
    LDA ?b11
    STA ?b3
    RTS

?mov32_l0_l3:
    LDA ?b12
    STA ?b0
    LDA ?b13
    STA ?b1
    LDA ?b14
    STA ?b2
    LDA ?b15
    STA ?b3
    RTS

?mov32_l1_l0:
    LDA ?b0
    STA ?b4
    LDA ?b1
    STA ?b5
    LDA ?b2
    STA ?b6
    LDA ?b3
    STA ?b7
    RTS

?mov32_l1_l1:
    LDA ?b4
    STA ?b4
    LDA ?b5
    STA ?b5
    LDA ?b6
    STA ?b6
    LDA ?b7
    STA ?b7
    RTS

?mov32_l1_l2:
    LDA ?b8
    STA ?b4
    LDA ?b9
    STA ?b5
    LDA ?b10
    STA ?b6
    LDA ?b11
    STA ?b7
    RTS

?mov32_l1_l3:
    LDA ?b12
    STA ?b4
    LDA ?b13
    STA ?b5
    LDA ?b14
    STA ?b6
    LDA ?b15
    STA ?b7
    RTS

?mov32_l2_l0:
    LDA ?b0
    STA ?b8
    LDA ?b1
    STA ?b9
    LDA ?b2
    STA ?b10
    LDA ?b3
    STA ?b11
    RTS

?mov32_l2_l1:
    LDA ?b4
    STA ?b8
    LDA ?b5
    STA ?b9
    LDA ?b6
    STA ?b10
    LDA ?b7
    STA ?b11
    RTS

?mov32_l2_l2:
    LDA ?b8
    STA ?b8
    LDA ?b9
    STA ?b9
    LDA ?b10
    STA ?b10
    LDA ?b11
    STA ?b11
    RTS

?mov32_l2_l3:
    LDA ?b12
    STA ?b8
    LDA ?b13
    STA ?b9
    LDA ?b14
    STA ?b10
    LDA ?b15
    STA ?b11
    RTS

?mov32_l3_l0:
    LDA ?b0
    STA ?b12
    LDA ?b1
    STA ?b13
    LDA ?b2
    STA ?b14
    LDA ?b3
    STA ?b15
    RTS

?mov32_l3_l1:
    LDA ?b4
    STA ?b12
    LDA ?b5
    STA ?b13
    LDA ?b6
    STA ?b14
    LDA ?b7
    STA ?b15
    RTS

?mov32_l3_l2:
    LDA ?b8
    STA ?b12
    LDA ?b9
    STA ?b13
    LDA ?b10
    STA ?b14
    LDA ?b11
    STA ?b15
    RTS

?mov32_l3_l3:
    LDA ?b12
    STA ?b12
    LDA ?b13
    STA ?b13
    LDA ?b14
    STA ?b14
    LDA ?b15
    STA ?b15
    RTS

; ------------------ add32 implementations ------------------
; lD = lD + lR  (handles carry across bytes)
?add32_l0_l0_l0:
    LDA ?b0
    ADDA ?b0
    STA ?b0
    LDA ?b1
    ADCA ?b1
    STA ?b1
    LDA ?b2
    ADCA ?b2
    STA ?b2
    LDA ?b3
    ADCA ?b3
    STA ?b3
    RTS

?add32_l0_l0_l1:
    LDA ?b0
    ADDA ?b4
    STA ?b0
    LDA ?b1
    ADCA ?b5
    STA ?b1
    LDA ?b2
    ADCA ?b6
    STA ?b2
    LDA ?b3
    ADCA ?b7
    STA ?b3
    RTS

?add32_l0_l0_l2:
    LDA ?b0
    ADDA ?b8
    STA ?b0
    LDA ?b1
    ADCA ?b9
    STA ?b1
    LDA ?b2
    ADCA ?b10
    STA ?b2
    LDA ?b3
    ADCA ?b11
    STA ?b3
    RTS

?add32_l0_l0_l3:
    LDA ?b0
    ADDA ?b12
    STA ?b0
    LDA ?b1
    ADCA ?b13
    STA ?b1
    LDA ?b2
    ADCA ?b14
    STA ?b2
    LDA ?b3
    ADCA ?b15
    STA ?b3
    RTS

; (and similarly for add where dest is l1,l2,l3)
?add32_l1_l1_l0:
    LDA ?b4
    ADDA ?b0
    STA ?b4
    LDA ?b5
    ADCA ?b1
    STA ?b5
    LDA ?b6
    ADCA ?b2
    STA ?b6
    LDA ?b7
    ADCA ?b3
    STA ?b7
    RTS

?add32_l1_l1_l1:
    LDA ?b4
    ADDA ?b4
    STA ?b4
    LDA ?b5
    ADCA ?b5
    STA ?b5
    LDA ?b6
    ADCA ?b6
    STA ?b6
    LDA ?b7
    ADCA ?b7
    STA ?b7
    RTS

?add32_l1_l1_l2:
    LDA ?b4
    ADDA ?b8
    STA ?b4
    LDA ?b5
    ADCA ?b9
    STA ?b5
    LDA ?b6
    ADCA ?b10
    STA ?b6
    LDA ?b7
    ADCA ?b11
    STA ?b7
    RTS

?add32_l1_l1_l3:
    LDA ?b4
    ADDA ?b12
    STA ?b4
    LDA ?b5
    ADCA ?b13
    STA ?b5
    LDA ?b6
    ADCA ?b14
    STA ?b6
    LDA ?b7
    ADCA ?b15
    STA ?b7
    RTS

?add32_l2_l2_l0:
    LDA ?b8
    ADDA ?b0
    STA ?b8
    LDA ?b9
    ADCA ?b1
    STA ?b9
    LDA ?b10
    ADCA ?b2
    STA ?b10
    LDA ?b11
    ADCA ?b3
    STA ?b11
    RTS

?add32_l2_l2_l1:
    LDA ?b8
    ADDA ?b4
    STA ?b8
    LDA ?b9
    ADCA ?b5
    STA ?b9
    LDA ?b10
    ADCA ?b6
    STA ?b10
    LDA ?b11
    ADCA ?b7
    STA ?b11
    RTS

?add32_l2_l2_l2:
    LDA ?b8
    ADDA ?b8
    STA ?b8
    LDA ?b9
    ADCA ?b9
    STA ?b9
    LDA ?b10
    ADCA ?b10
    STA ?b10
    LDA ?b11
    ADCA ?b11
    STA ?b11
    RTS

?add32_l2_l2_l3:
    LDA ?b8
    ADDA ?b12
    STA ?b8
    LDA ?b9
    ADCA ?b13
    STA ?b9
    LDA ?b10
    ADCA ?b14
    STA ?b10
    LDA ?b11
    ADCA ?b15
    STA ?b11
    RTS

?add32_l3_l3_l0:
    LDA ?b12
    ADDA ?b0
    STA ?b12
    LDA ?b13
    ADCA ?b1
    STA ?b13
    LDA ?b14
    ADCA ?b2
    STA ?b14
    LDA ?b15
    ADCA ?b3
    STA ?b15
    RTS

?add32_l3_l3_l1:
    LDA ?b12
    ADDA ?b4
    STA ?b12
    LDA ?b13
    ADCA ?b5
    STA ?b13
    LDA ?b14
    ADCA ?b6
    STA ?b14
    LDA ?b15
    ADCA ?b7
    STA ?b15
    RTS

?add32_l3_l3_l2:
    LDA ?b12
    ADDA ?b8
    STA ?b12
    LDA ?b13
    ADCA ?b9
    STA ?b13
    LDA ?b14
    ADCA ?b10
    STA ?b14
    LDA ?b15
    ADCA ?b11
    STA ?b15
    RTS

?add32_l3_l3_l3:
    LDA ?b12
    ADDA ?b12
    STA ?b12
    LDA ?b13
    ADCA ?b13
    STA ?b13
    LDA ?b14
    ADCA ?b14
    STA ?b14
    LDA ?b15
    ADCA ?b15
    STA ?b15
    RTS

; ------------------ load32 implementations (load from memory at X) ------------------
?load32_l0:
    LDA (0x0000,X)
    STA ?b0
    LDA (0x0001,X)
    STA ?b1
    LDA (0x0002,X)
    STA ?b2
    LDA (0x0003,X)
    STA ?b3
    RTS

?load32_l1:
    LDA (0x0000,X)
    STA ?b4
    LDA (0x0001,X)
    STA ?b5
    LDA (0x0002,X)
    STA ?b6
    LDA (0x0003,X)
    STA ?b7
    RTS

?load32_l2:
    LDA (0x0000,X)
    STA ?b8
    LDA (0x0001,X)
    STA ?b9
    LDA (0x0002,X)
    STA ?b10
    LDA (0x0003,X)
    STA ?b11
    RTS

?load32_l3:
    LDA (0x0000,X)
    STA ?b12
    LDA (0x0001,X)
    STA ?b13
    LDA (0x0002,X)
    STA ?b14
    LDA (0x0003,X)
    STA ?b15
    RTS
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

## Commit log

2023-12-07 This is the assembled ucode
2023-12-07 Add schematic picture of uct
    A hand made schematic of the uct. Sorry for the ppor quality just have my samsung table at hand. It gives an idea of the architecture.
2023-12-07 Add picture of the uct connected to Logic Analyzer to debug
    I had enought of single step dip switch debug sessions so i connected a logic analyzer and with some symbol definition i can do some reverse assembly of microcode.
2023-12-07 New repository for u code assembler
    Create new repository for micro code assembler and source file
2023-12-07 Add Op Code Assembler
2023-12-07 Fix name no space. Fix carriage return in lst file
2023-12-07 Update README.md
    Link to the schematic.
2023-12-07 Add io schematic
2023-12-07 correct reference to io schematic
2023-12-14 assembler now support indentation. Code cleaning. Readme grammar fix.
    change file extension to .asm for source code. Insert comment in the assembled listing. Assembler support indentation of mnemonic. Remove unused function. Fix grammar in readme.
2023-12-27 Add status check
    Verify status integrity in diag.
    Let comments and empty lines pass true micro assembler.
2024-03-08 Test the JRA jump foward case.
2024-03-27 Add Pass1 Symbol table creation assembler.
    The program recognize symbol starting in first colum and assign the current PC address to the symbol and add it to a directory. The Symbol table is printed on the console and the .lst file.
2025-03-13 Add Symbolic
    Add symbolic in assembler. Change immediate from ****H to 0x****
2025-03-14 Add relative jump
    ass assembler code to do relative address using symbol. Fix bug in ucode to increment msb IP.
2025-06-17 Update with PCB from PCBWAY sponsorship
    Add a picture of current Kicad work.
2025-06-25 PCBWAY logo.
    Add latest pcb with sponsor PCBWAY logo.
2025-06-30 Put Kicad schematic and board
    [MuCpu_counter.kicad_sch, MyCPU.kicad_sch, MyCpu_AddressData.kicad_sch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]
2025-07-01 Updated Fab in Kicad
2025-07-06 PCBWay Board assembled
    Add review
2025-07-10 Added wire-wrap back picture.
2025-12-20 Fail adding indirect indexing assembly
    Attempt to add indirect indexing to the assembler. Package FindInstructionIndex_old. Experiment with Rexex.
2026-01-03 Test LDA indexed indirect symbolic
    32-bit Fibonacci using library routines. Add ?clear32, ?load32, ?store32, ?mov32
    Restructure assembler.
2026-01-25 An LCD
    Modif Decode GAL, Add LCD init and print string.
2026-03-08 New instructions added
    16 bits diagnostic counter
    Add: CLRA, JRUGE, PSHA, POPA, LDA (SP-offset), LDX 16bits, LDX s. (8bit)
    LCD Print function for HexDigit, HexByte, Hex 16 bits,
2026-11-07 Add UART transmit
    Experiment with UART transmit
